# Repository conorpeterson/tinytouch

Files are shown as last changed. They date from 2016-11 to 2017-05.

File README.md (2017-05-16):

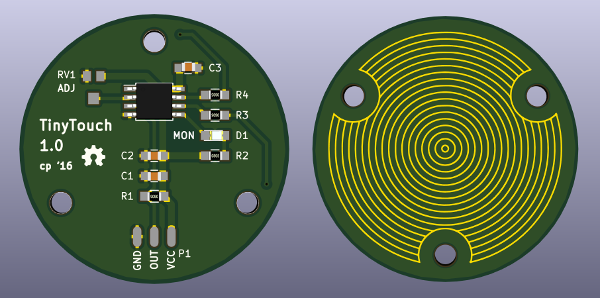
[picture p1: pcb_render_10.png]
pcb rendering

# TinyTouch
** Simple and reliable finger-to-PCB touch sensing **   
By Conor Peterson - conor.p.peterson@gmail.com 2016

License: Creative Commons Attribution-ShareAlike 4.0 International (CC BY-SA 4.0)

This project demonstrates simple and reliable on/off capacitive touch sensing. It is designed for use in interactive artworks or museum displays but would be well-suited for any hardwired application that requires oversized, physically accessible buttons located a distance from the controlling hardware.

The project is built around an ATtiny microcontroller so is compatible with 5v and 3.3v power supplies. The output of the detection unit is a clean high/low signal. Presses of variable duration are detected within reasonable limits.

The sensing element is built into the PCB itself and is designed to be directly touched by the user for maximum reliability. Material may be placed over the sensing element but should be kept thin, no thicker than typing paper (~.003" / .08mm). Certain materials may require adjustment of sensitivity threshold, or more substantial adaptations including the sensing element resistors (R3 and R4), the sampling interval or possibly the clock speed of the microcontroller.

One of the challenges in capacitive touch sensing is that the measurements tend to drift according to changes in temperature and humidity. This design attempts to address this by calibrating the detection floor at startup and at regular intervals thereafter. Consequently the sensor is best suited for momentary presses only - continuous contact for more than several seconds is to be avoided.

## Contents
### Firmware
This folder contains the source code for the ATtiny25/45/85 microcontroller. It has been tested to compile within a Linux environment using avr-gcc 4.9.2 and avr-libc 1.8.0. The bin subfolder contains pre-compiled hex files suitable for flashing with avrdude. NOTE: you must alter the fuse bits so that the chip runs at 8 MHz; this can be done by invoking the "fuses" target in the supplied makefile.

### Schematic
Contains a Kicad 4.x schematic for the project, plus a the reference PCB layout and fabrication-ready gerbers. The artwork in the TT_SMT_GRAPHICS subfolder can be modified and passed through Kicad's bitmap-to-component converter to create the custom touch sensor soldermask.

## License
The contents of this project are provided under the Creative Commons Attribution-ShareAlike 4.0 license.
(https://creativecommons.org/licenses/by-sa/4.0/legalcode)

You are free to:  
Share — copy and redistribute the material in any medium or format  
Adapt — remix, transform, and build upon the material for any purpose, even commercially.  
Under the following terms:  
Attribution — You must give appropriate credit, provide a link to the license, and indicate if changes were made. You may do so in any reasonable manner, but not in any way that suggests the licensor endorses you or your use.  
ShareAlike — If you remix, transform, or build upon the material, you must distribute your contributions under the same license as the original.

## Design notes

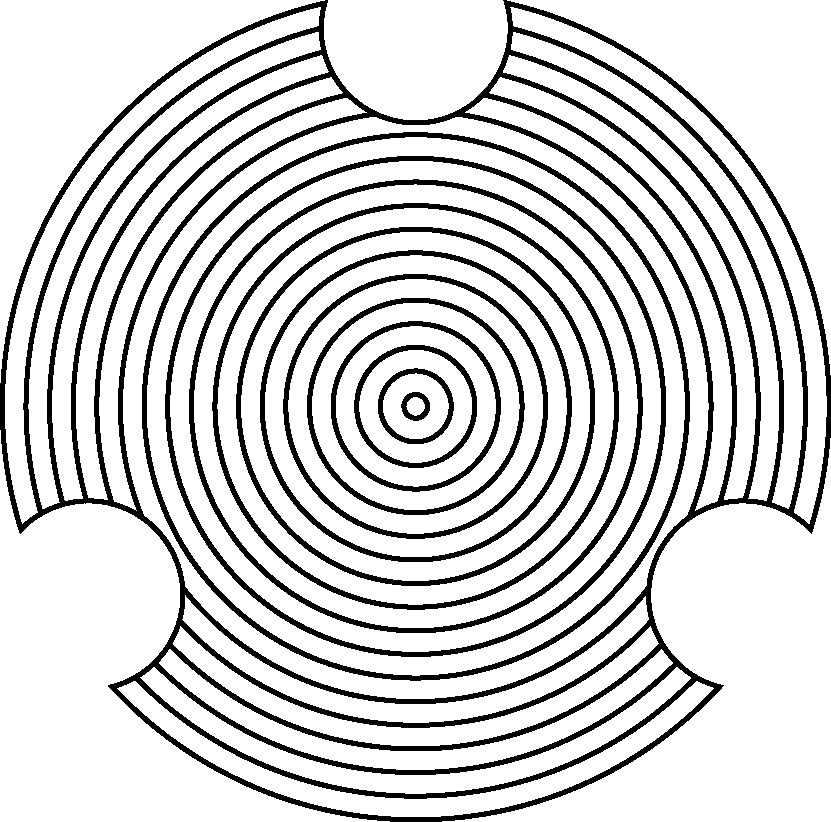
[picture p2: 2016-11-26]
Schematic/TT_SMT_GRAPHICS/TT_SMT_600dpi.png

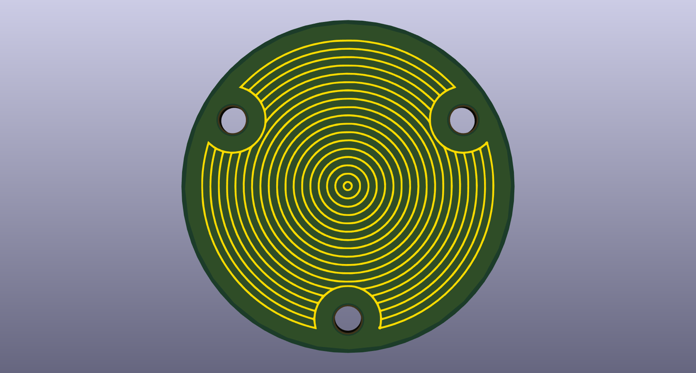
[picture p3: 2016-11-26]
pcb_render_10_rev.png

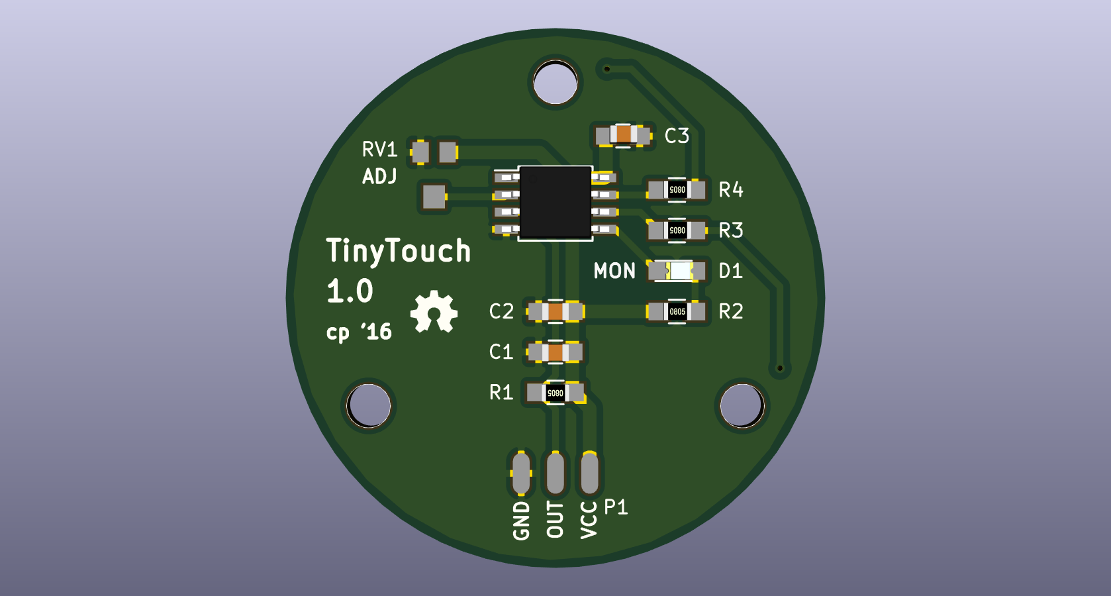
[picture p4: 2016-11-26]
pcb_render_10_front.png

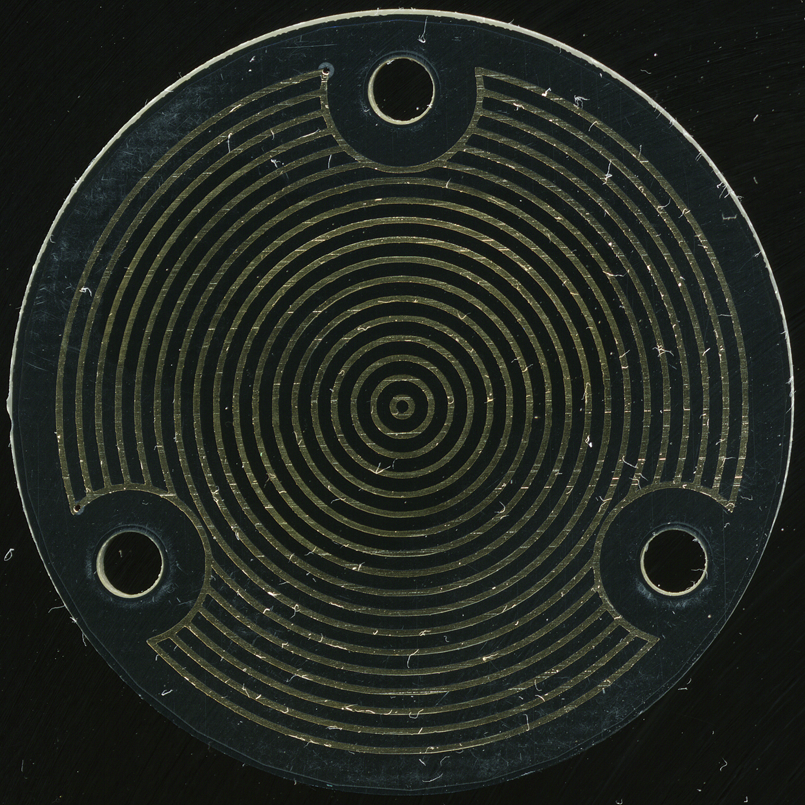
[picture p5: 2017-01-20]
pcb_scan_10_rev.png

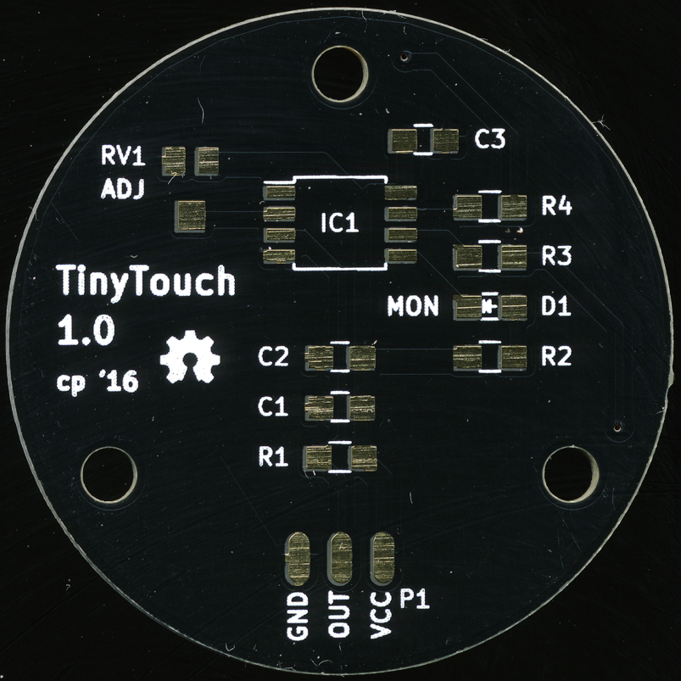
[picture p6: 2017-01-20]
pcb_scan_10_front.png

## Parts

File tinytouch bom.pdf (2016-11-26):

Bill of Materials

Page 1

## TinyTouch BOM

Prepared 2016 11/25

Ref. | Component Description | Package | Manu. | Manu. no. | Digikey part no. | Mouser part no. | Qty.
C1, C2 | Capacitor, ceramic, 22uF, 6.3v, X5R 0805 | Murata | GRM21BR60J226ME39L 490-1719-1-ND | 81-GRM21R60J226ME39L | 2
R1 | Resistor, carbon, 10k, 5% | 0805 | Yageo | RC0805JR-0710KL | 311-10KARCT-ND | 603-RC0805JR-0710KL | 1
R2 | Resistor, carbon, 2.2k, 5% | 0805 | Yageo | RC0805JR-072K2L | 311-2.2KARCT-ND | 603-RC0805JR-072K2L | 1
R3, R4 | Resistor, carbon, 1M, 5% | 0805 | Yageo | RC0805JR-071ML | 311-1.0MARCT-ND | 603-RC0805JR-071ML | 2
D1 | LED, yellow, diffused | 0805 | Osram | LY R976-PS-36 | 475-2560-1-ND | 720-LYR976-PS-36 | 1
C3 | Capacitor, ceramic, .1uF, 25V, X7R | 0805 | Kemet | C0805C104K3RACTU | 399-1168-1-ND | 80-C0805C104K3R | 1
RV1 | Potentiometer, 10k, 1 turn | SMD 3.3 x 3.7mm Bourns | TC33X-2-103E | TC33X-103ECT-ND | 652-TC33X-2-103E | 1
IC1 | ATtiny45 | SOIC 8, 5.3mm | Atmel | ATTINY45-20SUR | ATTINY45-20SURCT-ND 556-ATTINY45-20SU | 1

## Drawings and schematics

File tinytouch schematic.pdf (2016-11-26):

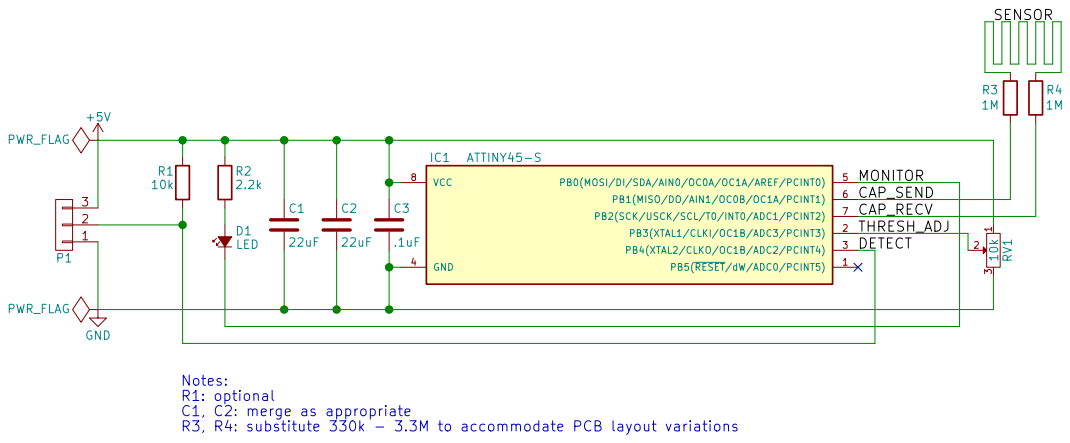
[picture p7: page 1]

C1, C2: merge as appropriate
R3, R4: substitute 330k - 3.3M to accommodate PCB layout variations

conor.p.peterson@gmail.com
File: TinyTouch.sch Sheet: / Conor Peterson

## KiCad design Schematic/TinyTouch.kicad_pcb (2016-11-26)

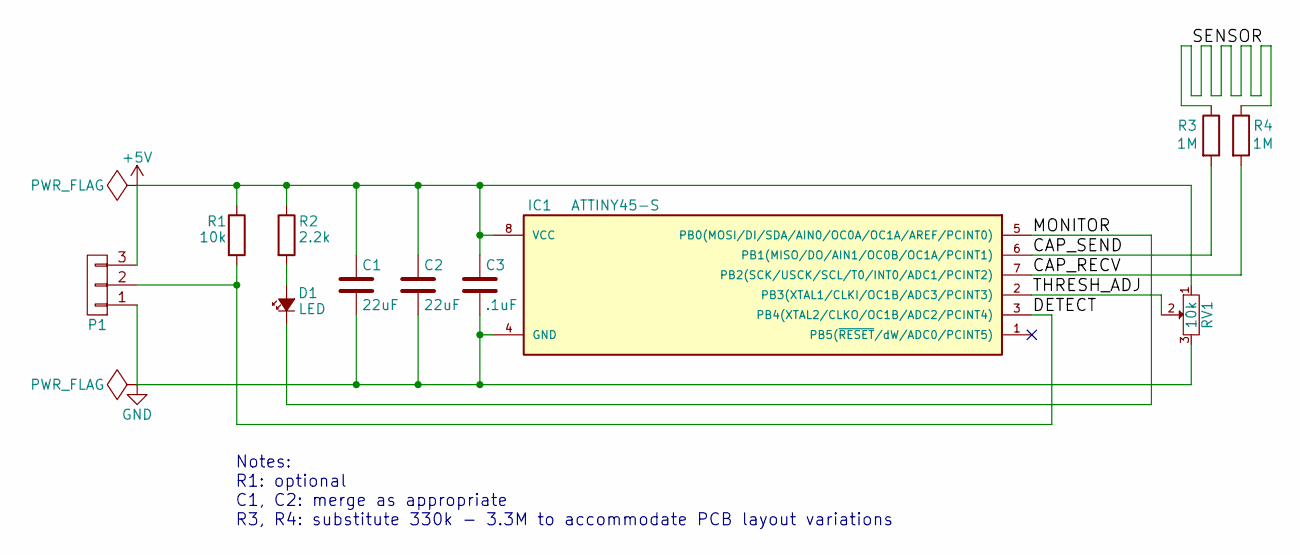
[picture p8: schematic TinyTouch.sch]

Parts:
C1, C2: 22uF; C_0805_HandSoldering
C3: .1uF; C_0805_HandSoldering
D1: LED; LED_0805_HandSoldering
IC1: ATTINY45-S; SOIJ-8_5.3x5.3mm_Pitch1.27mm
P1: CONN_01X03; CONN_1x3_DIRECTSOLDER
R1: 10k; R_0805_HandSoldering
R2: 2.2k; R_0805_HandSoldering
R3, R4: 1M; R_0805_HandSoldering
RV1: 10k; Bourns_SMD_Trimmer

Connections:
+5V: C1.1, C2.1, C3.1, IC1.8 (VCC), P1.3, R1.1, R2.1, RV1.1
/CAP_RECV: IC1.7 (PB2(SCK/USCK/SCL/T0/INT0/ADC1/PCINT2)), R4.2
/CAP_SEND: IC1.6 (PB1(MISO/DO/AIN1/OC0B/OC1A/PCINT1)), R3.2
/DETECT: IC1.3 (PB4(XTAL2/CLKO/OC1B/ADC2/PCINT4)), P1.2, R1.2
/MONITOR: D1.1 (K), IC1.5 (PB0(MOSI/DI/SDA/AIN0/OC0A/OC1A/AREF/PCI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)
/SENSOR: R3.1, R4.1
/THRESH_ADJ: IC1.2 (PB3(XTAL1/CLKI/OC1B/ADC3/PCINT3)), RV1.2
GND: C1.2, C2.2, C3.2, IC1.4 (GND), P1.1, RV1.3
unnamed: D1.2 (A), R2.2

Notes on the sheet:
Notes: R1: optional C1, C2: merge as appropriate R3, R4: substitute 330k - 3.3M to accommodate PCB layout variations

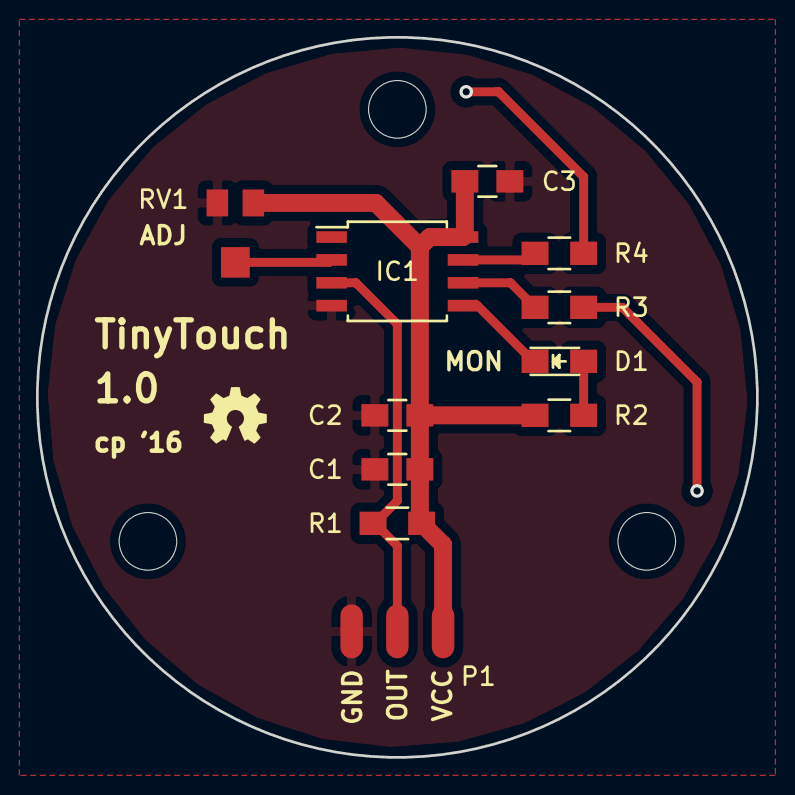
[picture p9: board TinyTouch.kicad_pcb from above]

Board: 2 copper layers, 40.0 x 40.0 mm, 15 parts (1 on the bottom side), 9 nets.

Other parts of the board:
SCREW_1, SCREW_2, SCREW_3: MountingHole_3.2mm_M3_ISO7380
SENS: LOGO; cap_touch_40mm

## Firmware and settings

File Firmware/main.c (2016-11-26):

/*
 * TinyTouch - main.c
 * (C) 2016 Conor Peterson
 * conor.p.peterson@gmail.com
 * http://www.conorpeterson.org
 * 
 * This software is licensed to you under the terms of the 
 * Creative Commons Attribution ShareAlike 4.0 International license
 * (CC BY-SA 4.0). See also https://creativecommons.org/licenses/by-sa/4.0/
 * 
 * You are free to share and adapt this software for any purpose, even commercially,
 * so long as you attribute the original author, and distribute your modifications
 * under the same license as the original.
 * 
 * 
 * This firmware runs on the TinyTouch, monitoring a capacitive touch sensor and
 * relaying the status via the DETECT line. The threshold is set via potentiometer
 * connected to ADC3 (PB4). Status of the sensor and detection is output on PB3
 * via PWM. Noise floor is adjusted automatically.
 * 
 * This firmware will run on any from the ATtiny25/45/85 line.
 * 
 */

#include <avr/io.h>
#include <util/delay.h>
#include <avr/interrupt.h>

//Major adjustments
#define WINDOW_LEN 8 //Store the last x readings for calculating touches. Power of 2.
#define NF_PERIOD 16 //Every NF_PERIOD samples, adjust the noise floor.

//Pin definitions - ATtiny25/45/85.
#define B_CAP_RECV	PB2
#define B_CAP_SEND	PB1
#define B_DETECT	PB4 //Externally pulled high, but driven normally
#define B_THRESH	PB3 //Set thresh via ADC3
#define B_MONITOR	PB0 //PWM visualizing via OC0A. Inverted logic.

//Port manipulation macros
#define SBI(port, pin) (port) |=  (1 << (pin))
#define CBI(port, pin) (port) &= ~(1 << (pin))

//Function definitions
void loop(void);
int main(void);
void adjust_threshold(void);
uint16_t sample(void);
int16_t sum_samples(void);
uint16_t sense(void);
ISR(TIMER1_COMPA_vect);
uint8_t analog_read(void);

//Global variables
int16_t noisefloor = 0;
uint8_t noisefloor_counter = NF_PERIOD;
int16_t samples[WINDOW_LEN];
uint8_t sample_cursor = 0;
uint8_t threshold = 3 * WINDOW_LEN;
volatile uint8_t event = 0;

//Interrupt on Timer1 OCIE1A controls the frequency of the sampling routine.
ISR(TIMER1_COMPA_vect)
{
	event = 1;
}

int main(void)
{
	cli(); //Disable interrupts
	
	//Timer1 is used for setting the sampling period.
	TCCR1 = _BV(CS13) | _BV(CS11) | _BV(CS10); //Prescale = /1024
	TCCR1 |= _BV(CTC1); //Clear timer on compare match C (freq. adj. via OCR1C)
	TIMSK = _BV(OCIE1A); //Interrupt on compare match A
	OCR1A = 0; //Request interrupt when TNCT1 rolls over to zero
	OCR1C = 161; //OCR1C adjusts of Timer1 -- NOTE approximately what frequency is this, 50Hz?
	
	//Timer0 is used for visualizing the state of the sensor via PWM-faded LED
	TCCR0A = _BV(WGM01) | _BV(WGM00); //Fast PWM mode with TOP as 0xFF (adjustable duty cycle mode)
	TCCR0A |= _BV(COM0A1) | _BV(COM0A0); //Set OC0A at compare match, clear OC0A at bottom (inverting mode)
	TCCR0B = _BV(CS01) | _BV(CS00); //Prescale /64
	OCR0A = 128; //Almost immediately overridden, but can help catch early hangs
	SBI(DDRB, B_MONITOR); //B_MONITOR as an output
	
	//ADC3 is used to adjust the sensitivity
	ADMUX = _BV(MUX1) | _BV(MUX0); //ADC3 (PB3 or pin 2)
	ADMUX |= _BV(ADLAR); //Left-adjusted results (8-bit mode)
	ADCSRA = _BV(ADEN); //Enable ADC
	ADCSRA |= _BV(ADPS1) | _BV(ADPS0); //ADC clock prescaled by /8
	DIDR0 = _BV(ADC3D); //Disable digital IO on ADC3 to save power
	
	//Pin configuration
	SBI(DDRB, B_DETECT); //B_DETECT as output
	CBI(PORTB, B_DETECT); //B_DETECT driven low
	
	//Establish baselines for the noisefloor and trigger threshold
	noisefloor = sample();
	adjust_threshold();
	
	sei();	//Enable interrupts
	
	for(;;) {
		loop();
	}

	return 0; //Never reached
}

void loop(void)
{
	int16_t reading;
	int16_t area;

	while( !event ) {};
	event = 0;
	
	reading = sample();
	
	if( ++noisefloor_counter >= NF_PERIOD ) {
		noisefloor_counter = 0;
		if( reading != noisefloor ) {
			noisefloor += (reading > noisefloor) ? 1 : -1;
		}
		
		//Occasionally sample ADC3 and adjust the threshold
		adjust_threshold();
	}
	
	reading -= noisefloor;
	
	samples[sample_cursor++] = reading;
	sample_cursor &= WINDOW_LEN;

	area = sum_samples();

	if( area > 0 ) {
		if( area > 255 || area > threshold ) {
			OCR0A = 255;
		} else {
			OCR0A = area; //Update monitor
		}
	} else {
		OCR0A = 0;
	}

    if( area > threshold ) {
		SBI(PORTB, B_DETECT); //B_DETECT driven HIGH
	} else {
		CBI(PORTB, B_DETECT); //B_DETECT driven LOW
	}
}

uint8_t analog_read(void)
{
	SBI(ADCSRA, ADSC); //Start conversion
	while( ADCSRA & _BV(ADSC) ) {}; //Wait for conversion to end
	return ADCH;
}

//Whenever a new sample is logged, it and several preceeding samples are summed and
//compared to threshold. I ran several experiments and found a useful range between 
//8 (WINDOW_LEN * 1) and 64 (WINDOW_LEN * 8), with a good compromise at 24 (WINDOW_LEN * 3).
//The threshold is adjusted by setting an analog pot, which is sampled and remapped every
//few sensing intervals.
void adjust_threshold(void)
{
	uint8_t value;
	value = analog_read();
	threshold = value;
}

//4X oversampling to reduce noise
uint16_t sample(void)
{
	uint32_t accum = 0;
	accum = sense();
	accum += sense();
	accum += sense();
	accum += sense();
	accum >>= 2;
	return (uint16_t)accum;
}

int16_t sum_samples(void)
{
	uint8_t i;
	int16_t accum = 0;
	for(i = 0; i < WINDOW_LEN; i++) {
		accum += samples[i];
	}
	return accum;
}

uint16_t sense(void)
{
	uint16_t counter = 0;
	
	//Totally discharge the sensor
	SBI(DDRB, B_CAP_SEND);  //Send as output
	SBI(DDRB, B_CAP_RECV);  //Receive as output

	CBI(PORTB, B_CAP_SEND); //Drive send LOW
	CBI(PORTB, B_CAP_RECV); //Drive receive LOW
	_delay_us(50); //wait...

	//Charge the sensor and watch the rise time.
	CBI(DDRB, B_CAP_RECV); //Recv now an input
	cli(); //Disable interrupts
	SBI(PORTB, B_CAP_SEND); //Drive send HIGH
	while( (PINB & _BV(B_CAP_RECV)) == 0  ) {
		counter++;
		//Catch timeouts - testing against zero appears free in assembled output.
		if( counter == 0 ) {
			break;
		}
	}
	sei(); //Re-enable interrupts
	//Finish the charge to VCC
	SBI(PORTB, B_CAP_RECV); //Recv pull-up on
	SBI(DDRB, B_CAP_RECV); //Recv as output
	_delay_us(50);
	CBI(DDRB, B_CAP_RECV); //Recv as input
	CBI(PORTB, B_CAP_RECV); //Recv floating
	cli(); //Disable interrupts
	CBI(PORTB, B_CAP_SEND); //Drive send LOW
	while( (PINB & _BV(B_CAP_RECV)) != 0 ) {
		counter++;
		if( counter == 0 ) {
			break;
		}
	}
	sei(); //Re-enable interrupts
	return counter;
}

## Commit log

2017-01-20 Added scans of the PCB itself
2017-02-05 More conservative fuses in Makefile
